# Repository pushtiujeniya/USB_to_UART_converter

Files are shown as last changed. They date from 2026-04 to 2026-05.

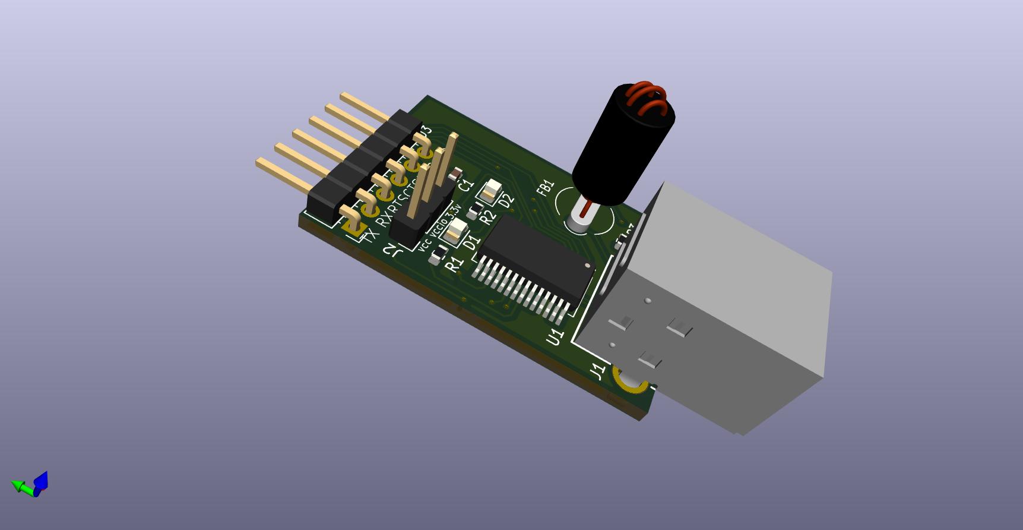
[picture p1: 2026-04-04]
3D view/3D_side.jpg

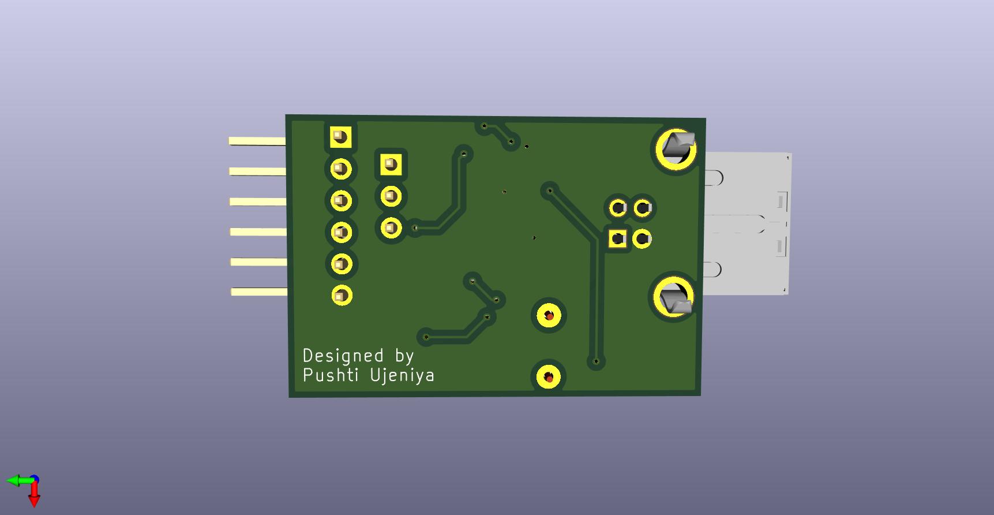
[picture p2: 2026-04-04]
3D view/3D_bottom.jpg

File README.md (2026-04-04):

# USB_to_UART_converter
-----------------------
USB to UART converter module convert USB data to UART using FT232RL IC.

# Hardware components used
--------------------------
- FT232RL (28 pin package) from FTDI
- 3 pin connector for USB bus power with  selectable external supply so one can select the supply between 3.3V or 5V DC
- Ferrite bead
- 2 smd led for TX and RX data transmission indication
- 6 pin MCU connector
- USB-B (USB TYPE-B) USB 2.0 Receptacle Connector 4 Position Through Hole 
- resistors
- capacitors

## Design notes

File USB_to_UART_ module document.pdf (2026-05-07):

USB to UART module

USB to UART converter module convert USB data getting from connector and then convert to UART using FT232RL IC.

Hardware components used
FT232RL (28 pin package) from FTDI
3 pin connector for USB bus power with selectable external supply so one can select the supply between 3.3V or 5V DC
Ferrite bead
2 smd led for TX and RX data transmission indication with 330ohm resistor for led protection
6 pin MCU connector which is for uart connection
USB-B (USB TYPE-B) USB 2.0 Receptacle Connector 4 Position Through Hole
resistors
Capacitors

PINOUT OF FT232RL

USBDP= USB data signal plus USBDM= USB data signal minus

gnd= device ground supply pins
VCC=3.3V to 5.25V input supply range
3v3out= this IC has internal voltage regulator which gives output of 3.3v Connect this pin to ground by using 100nF

vccio= pin to decide which voltage value the i/o pins should be use Either 3.3v or 5v
This is used when there is no MCU fixed used

3.3V logic= when vccio pin is connected to 3v3out pin
5 v logic= when vccio pin is connected to vcc

AGND= analog ground supply for internal clock multiplier

DTR= data terminal ready
RTS= handshake signal = it means ready to send
DSR= data set ready
CTS= clear to send

Test pin= puts ic into test mode
For normal connection test pin is connected with gnd

RTS(request to send)

Used to prevent the data loss when one device is faster than other
Used for handshaking before sending and receive the data with MCU

When ic wants to send data it creates RTS low which tells the MCU that I want to send data

If MCU is ready to receive the data CTS(clear to send)=low

USb power pin with= vcc of ic but with ferrite bead si that it can reduce noise

USB CONNECTOR PINOUT

vcc= the main input power supply

D+= for data +
Connect with MCU USB data + pin

D- = for data -
Connect with MCU USB data - pin

gnd= direct connect to ground

Shield= metal part body of the USB connector which will collect the electric discharge from the human touch or environment

Why shield pin should not connect direct to gnd
As the shield pin is the metal core body part which will collect the electric discharge from the human touch or environment so sudden discharge can cause voltage drop
there fore to reduce the votlage drop the resistor and capacitor parallel connection is used

Shield pin can connect directly to gnd but good method is R+C combination in parallel connection with shield then to gnd
capacitor= used to prevent high frequency EMI noise so EMI noise can goes to gnd resistor= slowly removes the static charge from the shield

Ferrite bead

It converts high frequency noise into heat
Placed in series with vcc line
Used in switching regulator LDO, USB
Placed near with connector like USB type C is used then it should place near with connector

Decoupling capacitor at 3v3out pin

Reason of choosing FT2323RL ic

The usb to uart conversion can be done also by CH340 ic or CP2102 ic
Advantages of FT232RL
- Stable drivers for macos, windows, linux so no need to install manually drivers while in other ic there is need of downloading manual driver for older system
- High tolerance for EMI noise and other signals
- Configurable via EEPROM
- Robust to use in harsh environment also
- Well defined Internal structure

Disadvantage of FT232RL

Very high price compare to other ic

UART connector

1X6 pin header 2.54mm pitch distance connector for UART

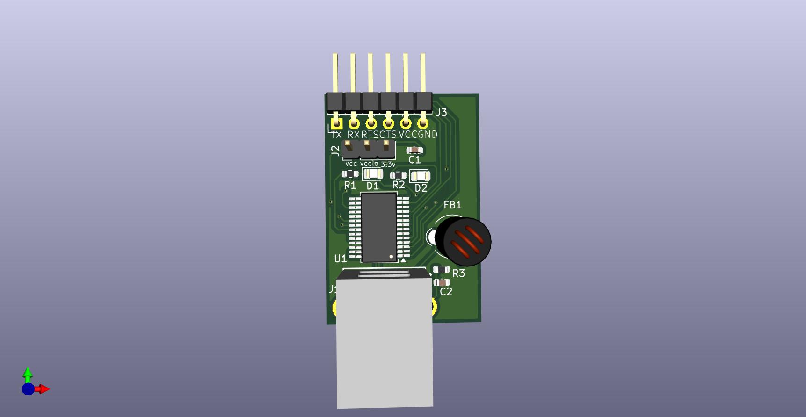
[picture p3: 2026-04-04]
3D view/3D_top.jpg

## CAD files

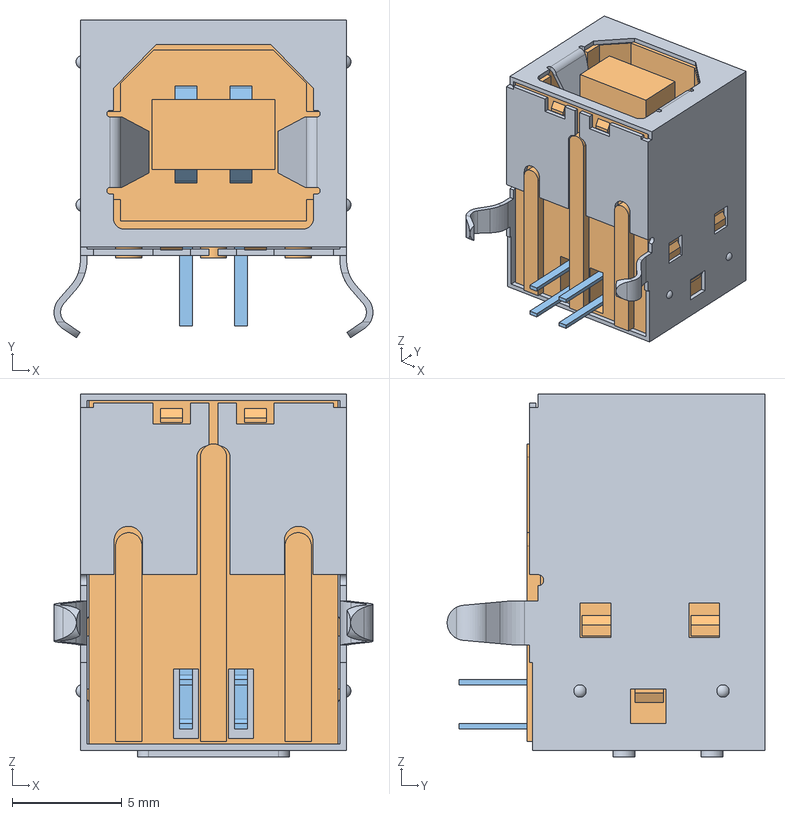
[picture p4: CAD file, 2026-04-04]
External library/USB-B-S-F-B-TH-FR.stp
14.5 x 14.4 x 16.5 mm
USB-B-S-TH_S
USB-B-S-B-TH_B
USB-B-S-TH_P

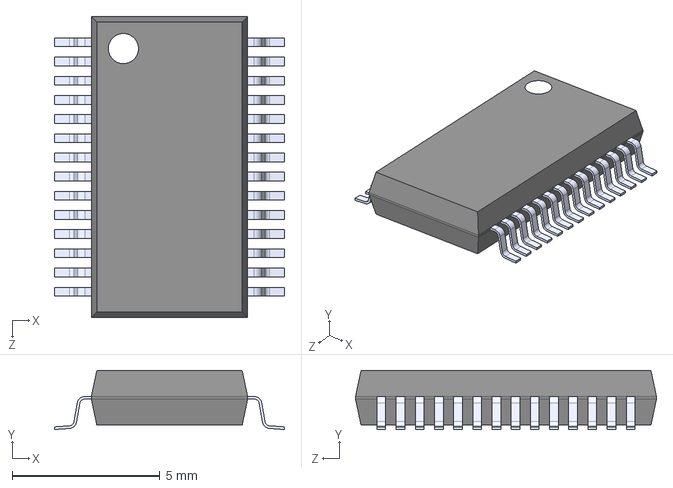
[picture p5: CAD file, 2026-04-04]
External library/INTERFACE-FT232RL_SSOP28_.step
7.80 x 2.00 x 10.2 mm

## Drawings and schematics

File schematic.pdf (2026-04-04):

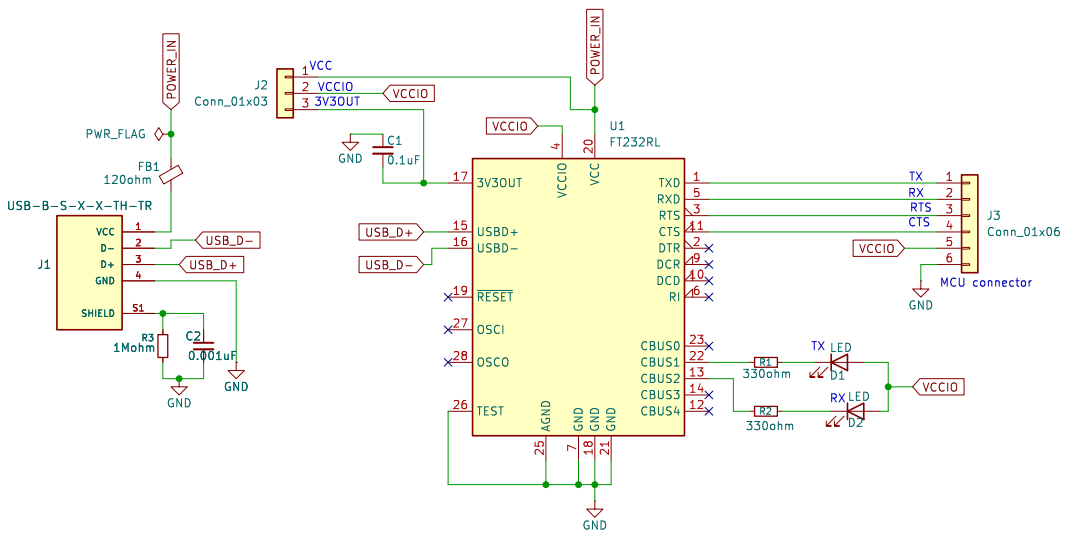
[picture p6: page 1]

7 VCC 20 GND 18 GND 21 TXD 1 RXD 5 RTS 3 CTS 11 DTR 2 DCR 9 DCD 10 RI 6 CBUS0 23 CBUS1 22 CBUS2 13 CBUS3 14 CBUS4 12 U1 FT232RL USB_D- VCCIO

File: USB_to_UART.kicad_sch Sheet: / By Pushti Ujeniya

Id: 1/1 Title: USB to UART converter using FT232RL

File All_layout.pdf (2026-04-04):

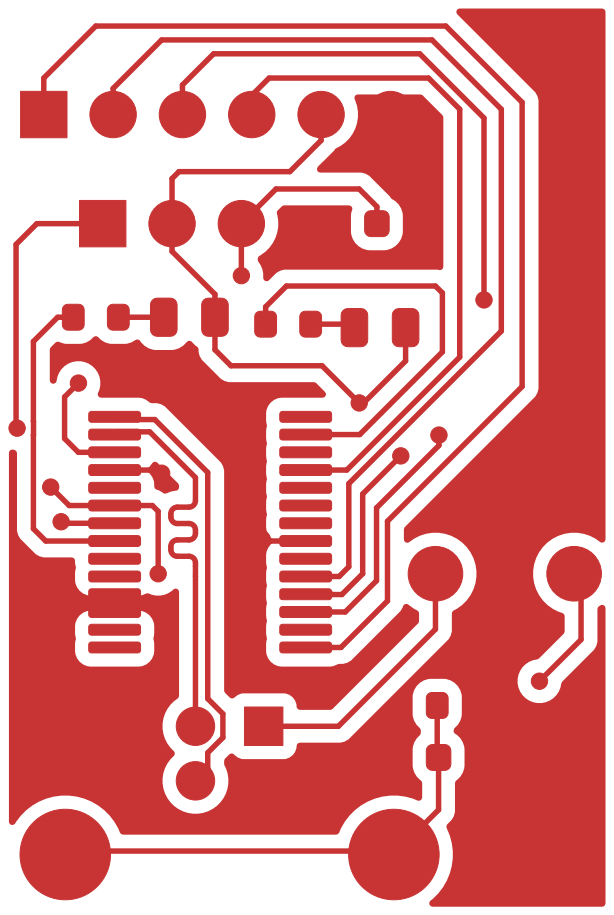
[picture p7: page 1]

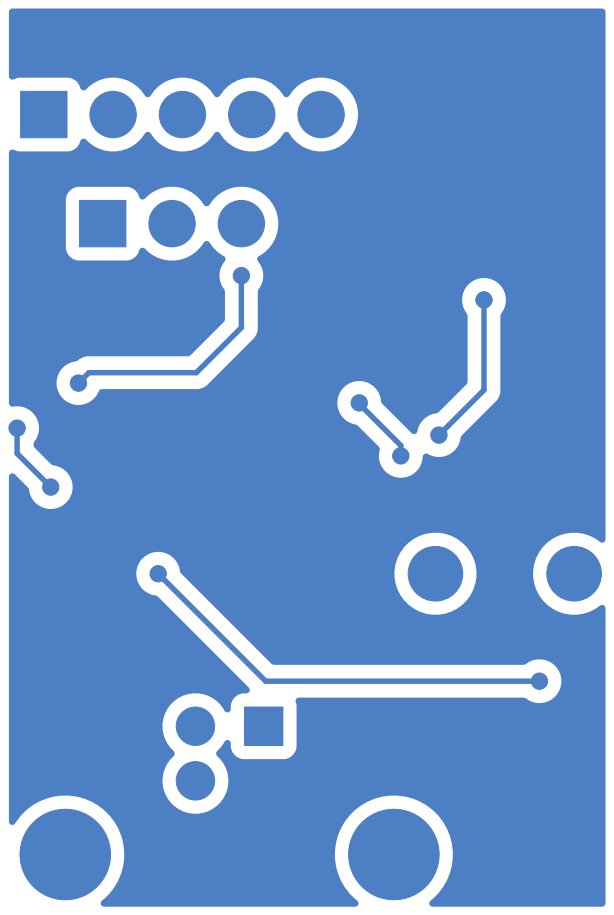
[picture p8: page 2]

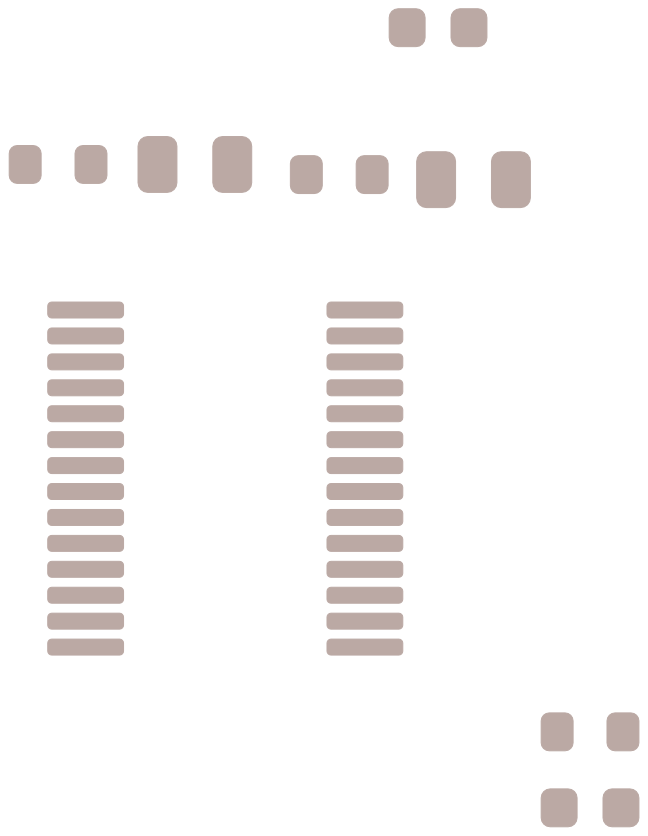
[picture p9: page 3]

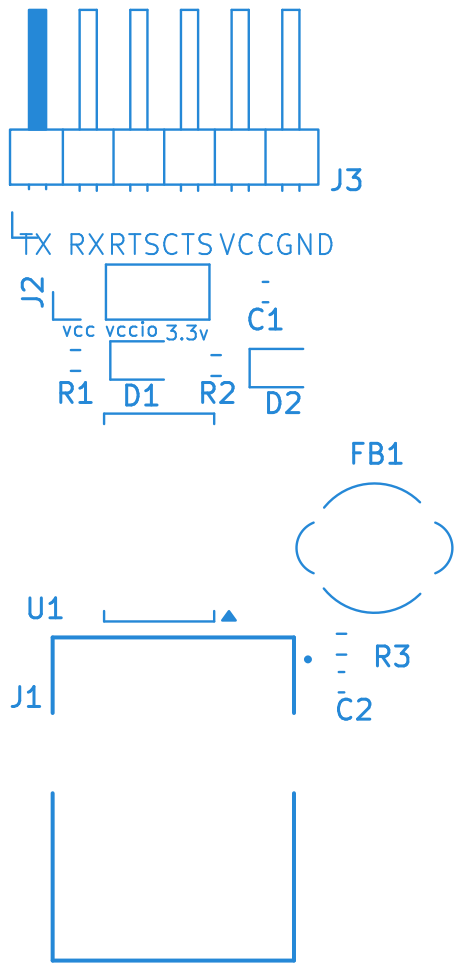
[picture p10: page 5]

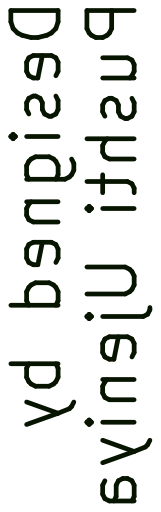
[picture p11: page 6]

Designed by Pushti Ujeniya

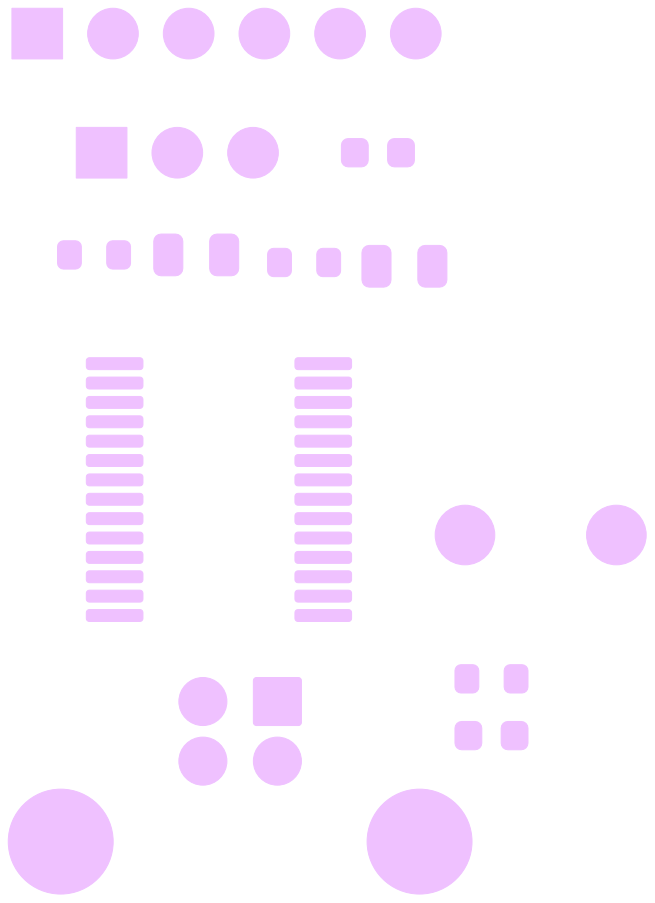
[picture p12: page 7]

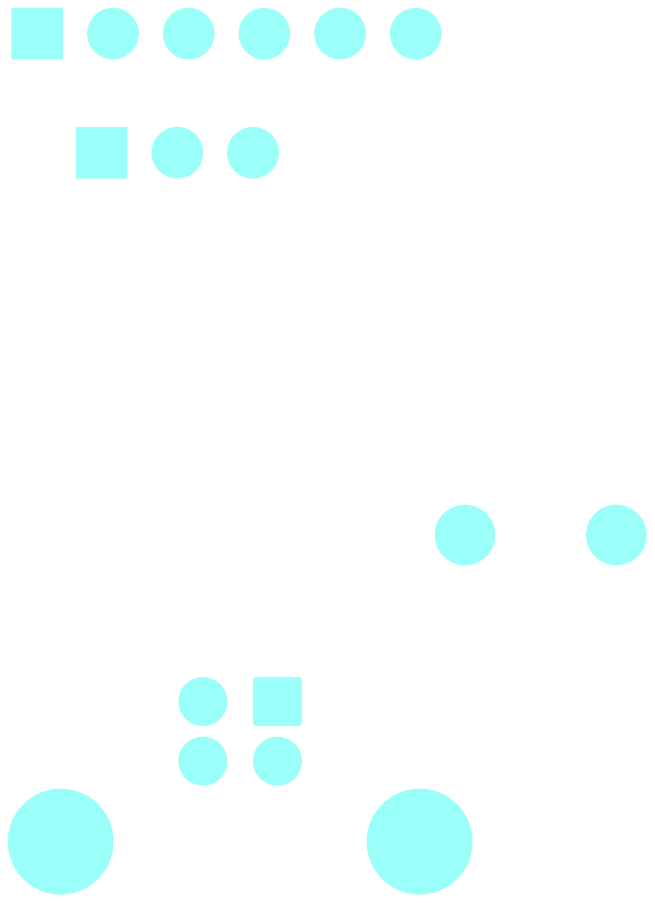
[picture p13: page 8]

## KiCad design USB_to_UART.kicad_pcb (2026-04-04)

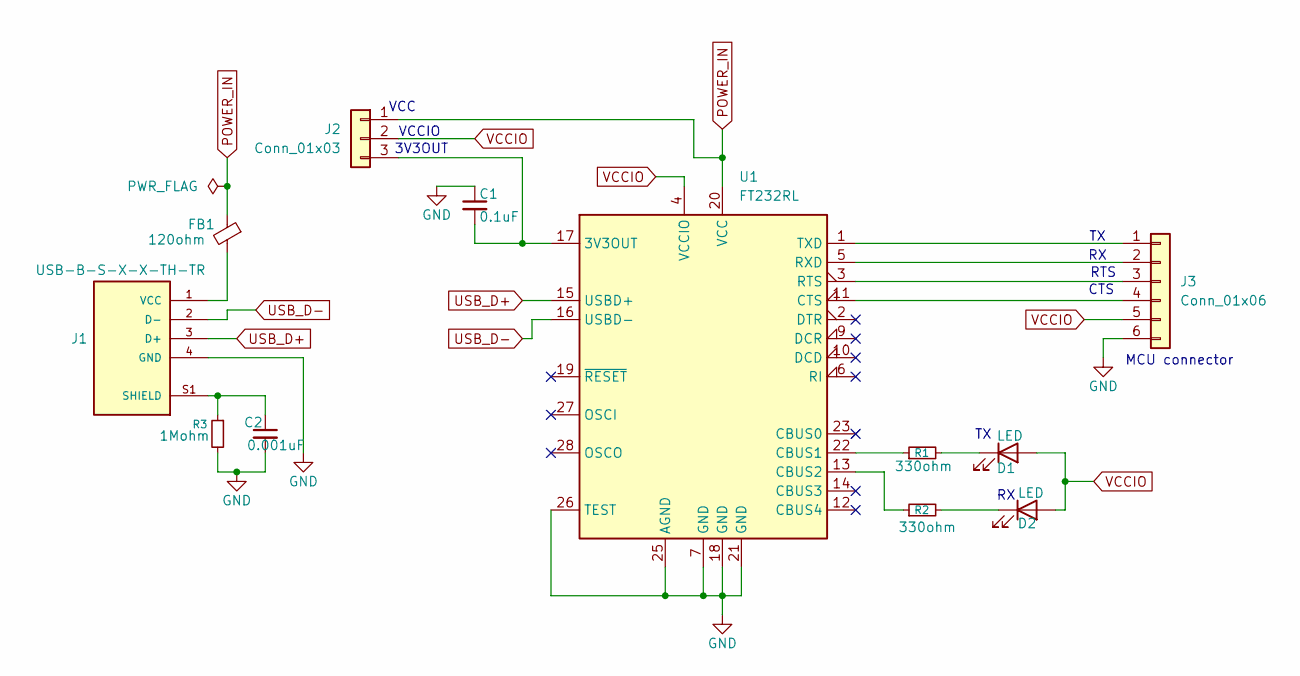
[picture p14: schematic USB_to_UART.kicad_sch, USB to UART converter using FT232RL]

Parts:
C1: 0.1uF; C_0603_1608Metric
C2: 0.001uF; C_0603_1608Metric
D1, D2: LED; LED_0805_2012Metric
FB1: 120ohm; LairdTech_28C0236-0JW-10
J1: USB-B-S-X-X-TH-TR; SAMTEC_USB-B-S-X-X-TH-TR; PARTREV Q
J2: Conn_01x03; PinHeader_1x03_P2.54mm_Vertical
J3: Conn_01x06; PinHeader_1x06_P2.54mm_Horizontal
R1, R2: 330ohm; R_0603_1608Metric
R3: 1Mohm; R_0603_1608Metric
U1: FT232RL; SSOP-28_5.3x10.2mm_P0.65mm

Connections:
GND: C1.1, C2.2, J1.4 (GND), J3.6, R3.2, U1.7 (GND), U1.18 (GND), U1.21 (GND), U1.25 (AGND), U1.26 (TEST)
unnamed: C2.1, J1.S1 (SHIELD), J1.S2 (SHIELD), R3.1
unnamed: D1.1 (K), R1.2
unnamed: D2.1 (K), R2.2
unnamed: FB1.2, J1.1 (VCC)
unnamed: C1.2, J2.3, U1.17 (3V3OUT)
unnamed: J3.1, U1.1 (TXD)
unnamed: J3.2, U1.5 (RXD)
unnamed: J3.3, U1.3 (RTS)
unnamed: J3.4, U1.11 (CTS)
unnamed: R1.1, U1.22 (CBUS1)
unnamed: R2.1, U1.13 (CBUS2)
POWER_IN: FB1.1, J2.1, U1.20 (VCC)
USB_D+: J1.3 (D+), U1.15 (USBD+)
USB_D-: J1.2 (D-), U1.16 (USBD-)
VCCIO: D1.2 (A), D2.2 (A), J2.2, J3.5, U1.4 (VCCIO)

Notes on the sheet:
VCCIO
CTS
RTS
VCC
MCU connector
3V3OUT

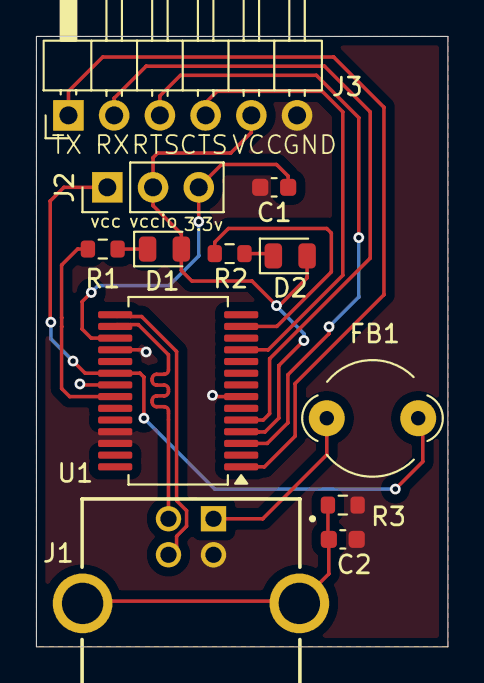
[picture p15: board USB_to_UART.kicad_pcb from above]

Board: 2 copper layers, 22.9 x 33.9 mm, 12 parts (0 on the bottom side), 16 nets.

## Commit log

2026-04-04 schematic and all layout pdf added
2026-04-04 schematic file added
    [USB_to_UART.kicad_sch]
2026-04-04 layout file added
    [USB_to_UART.kicad_pcb]
2026-04-04 usb to uart pro files
2026-04-04 external library files added
    [INTERFACE-FT232RL_SSOP28_.step, USB-B-S-F-B-TH-FR.stp]
2026-04-04 external library files added
    [INTERFACE-FT232RL_SSOP28_.step, USB-B-S-F-B-TH-FR.stp]
2026-04-04 Update README with USB to UART converter details
    Added detailed description of the USB to UART converter and its hardware components.
2026-04-04 Update README with USB-B connector details
2026-05-07 USB to UART converter document

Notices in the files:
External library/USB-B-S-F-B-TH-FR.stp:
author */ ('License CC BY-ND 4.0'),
